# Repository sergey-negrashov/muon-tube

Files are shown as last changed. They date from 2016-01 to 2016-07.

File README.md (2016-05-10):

# MuonTube. Geiger based muon detector for art and science. 
In this project I aim to design and develop a standalone muon detector using old Soviet STS-5  Geiger tubes.  Geometry is shown bellow:
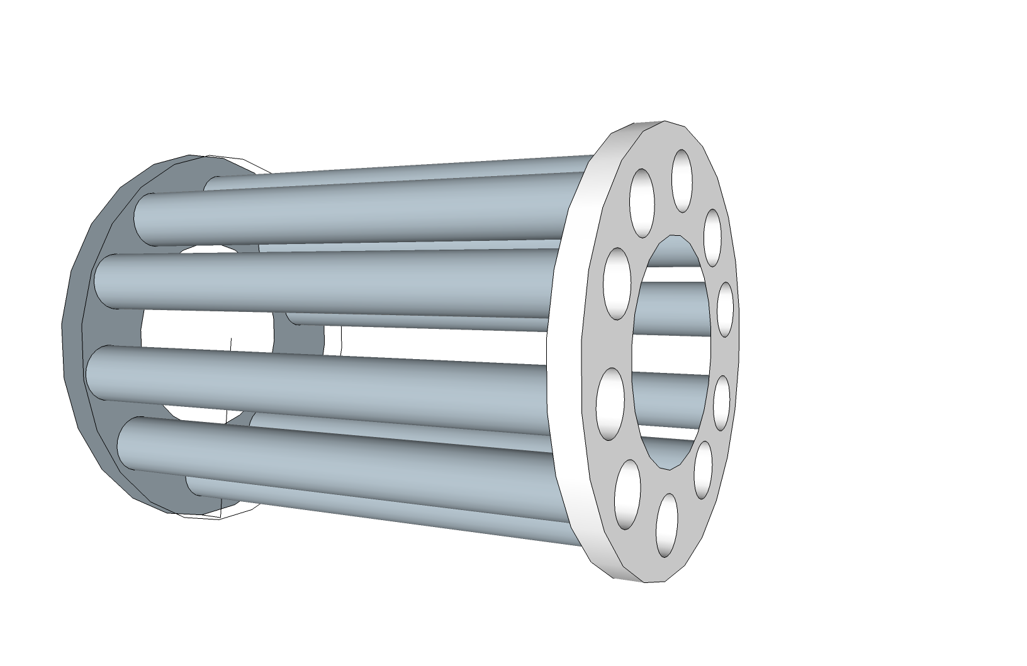
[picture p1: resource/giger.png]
Geiger Detector Geometry


# Roadmap:
1. Power supply design. (Done)
2. Data acquisition design. (Work in progress)
3. Mechanical design. (Started)
4. Integration.

I intend to use custom electronics for the PSU and DAQ. Most likely driven by an FPGA. 
PDF for the PSU and the bias circuit for the GM tube now available [obsolete new one comming soon](https://github.com/sergey-negrashov/muon-tube/raw/master/Schematics/PSU.pdf)

# Goodies 
Geiger tube cage:
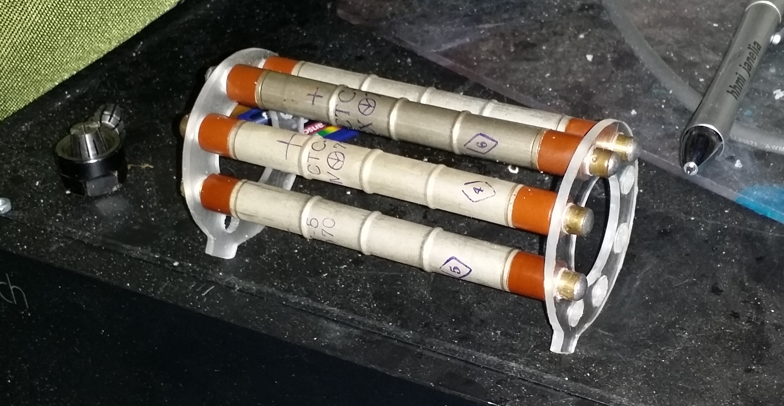
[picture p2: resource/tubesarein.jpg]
Geiger Geiger tube cage


Freshly milled HV PSU board:
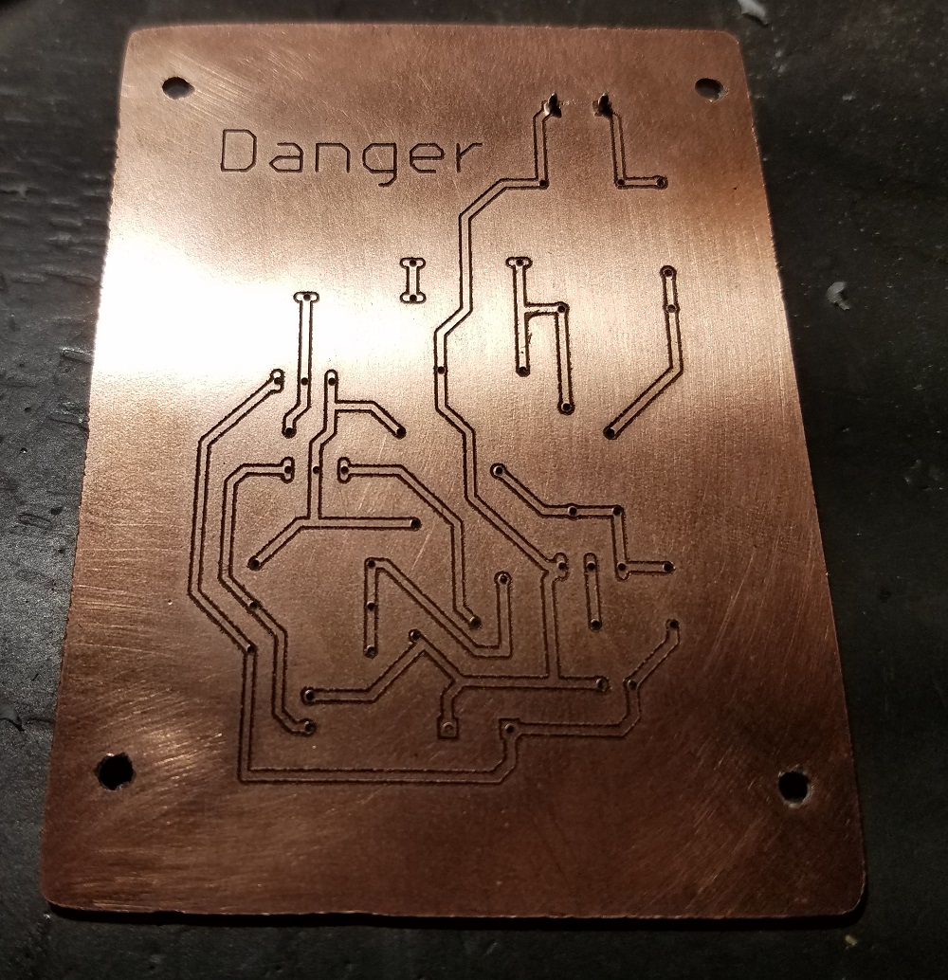
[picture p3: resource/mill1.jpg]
Geiger Freshly milled HV PSU board


First Muons?

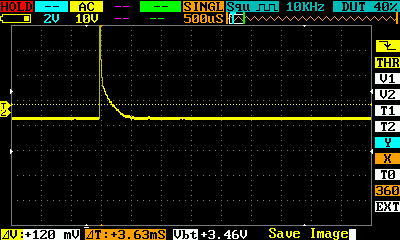
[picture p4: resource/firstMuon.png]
Muon First Muon


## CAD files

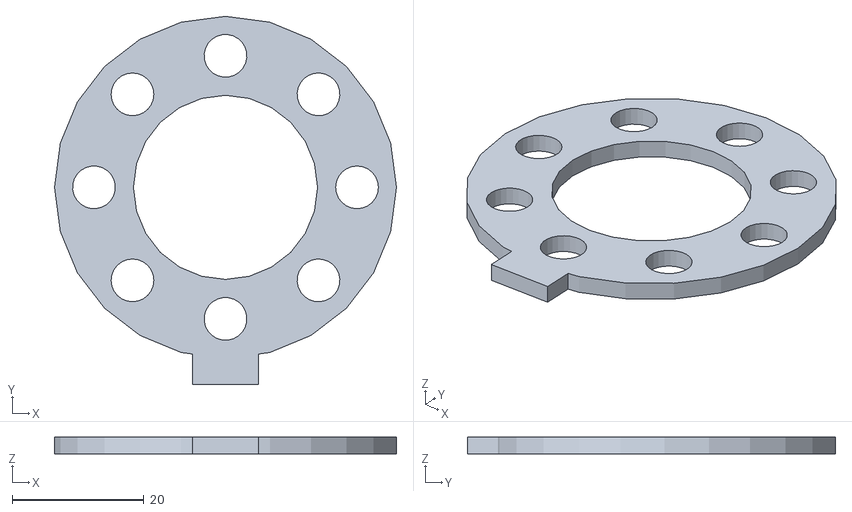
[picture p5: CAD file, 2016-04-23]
Mechanical/cylinder.stl
52.0 x 56.0 x 2.54

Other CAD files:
Mechanical/cylinder.skp

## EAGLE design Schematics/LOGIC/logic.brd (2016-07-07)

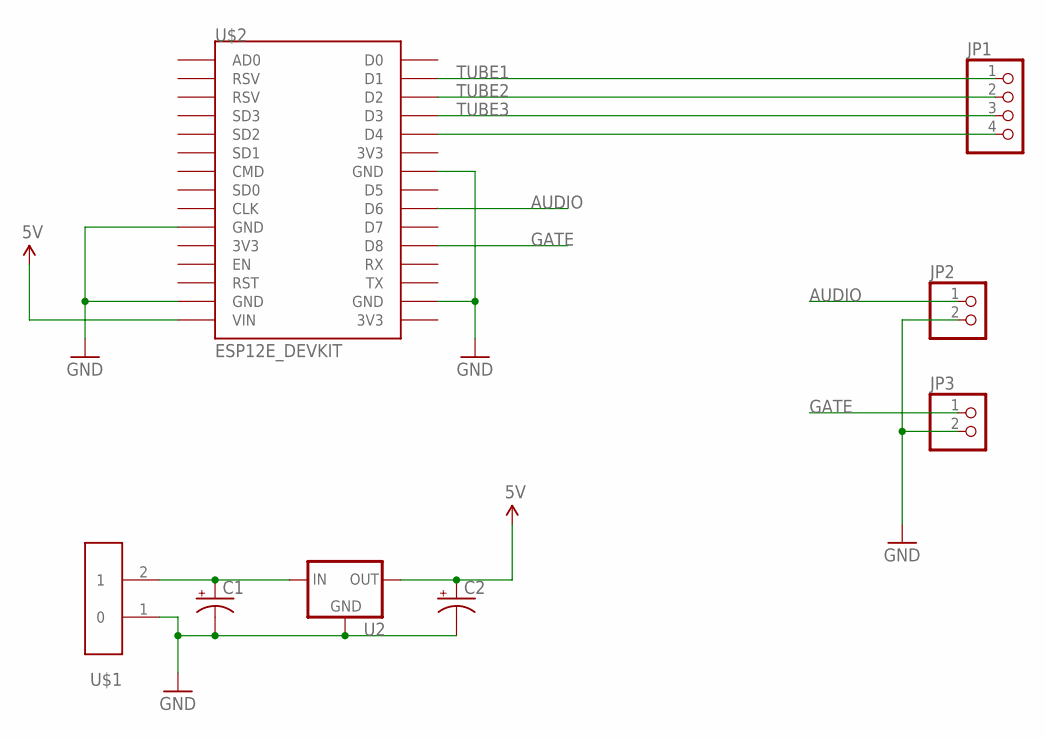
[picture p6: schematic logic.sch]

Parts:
C1, C2: 10UF-25V-20%(PTH); CPOL-RADIAL-10UF-25V
JP1: PINHD-1X4; 1X04
JP2, JP3: PINHD-1X2; 1X02
U2: V_REG_78XXSINK; TO220-IGO
U$1: ED2609
U$2: ESP12E_DEVKIT

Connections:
5V: C2.1 (+), U2.OUT, U$2.VIN
AUDIO: JP2.1, U$2.D6
GATE: JP3.1, U$2.D8
GND: C1.2 (-), C2.2 (-), JP2.2, JP3.2, U2.GND, U$1.1 (0), U$2.GND@0 (GND), U$2.GND@1 (GND), U$2.GND@2 (GND), U$2.GND@3 (GND)
unnamed: C1.1 (+), U2.IN, U$1.2 (1)
unnamed: JP1.4, U$2.D4
TUBE1: JP1.1, U$2.D1
TUBE2: JP1.2, U$2.D2
TUBE3: JP1.3, U$2.D3

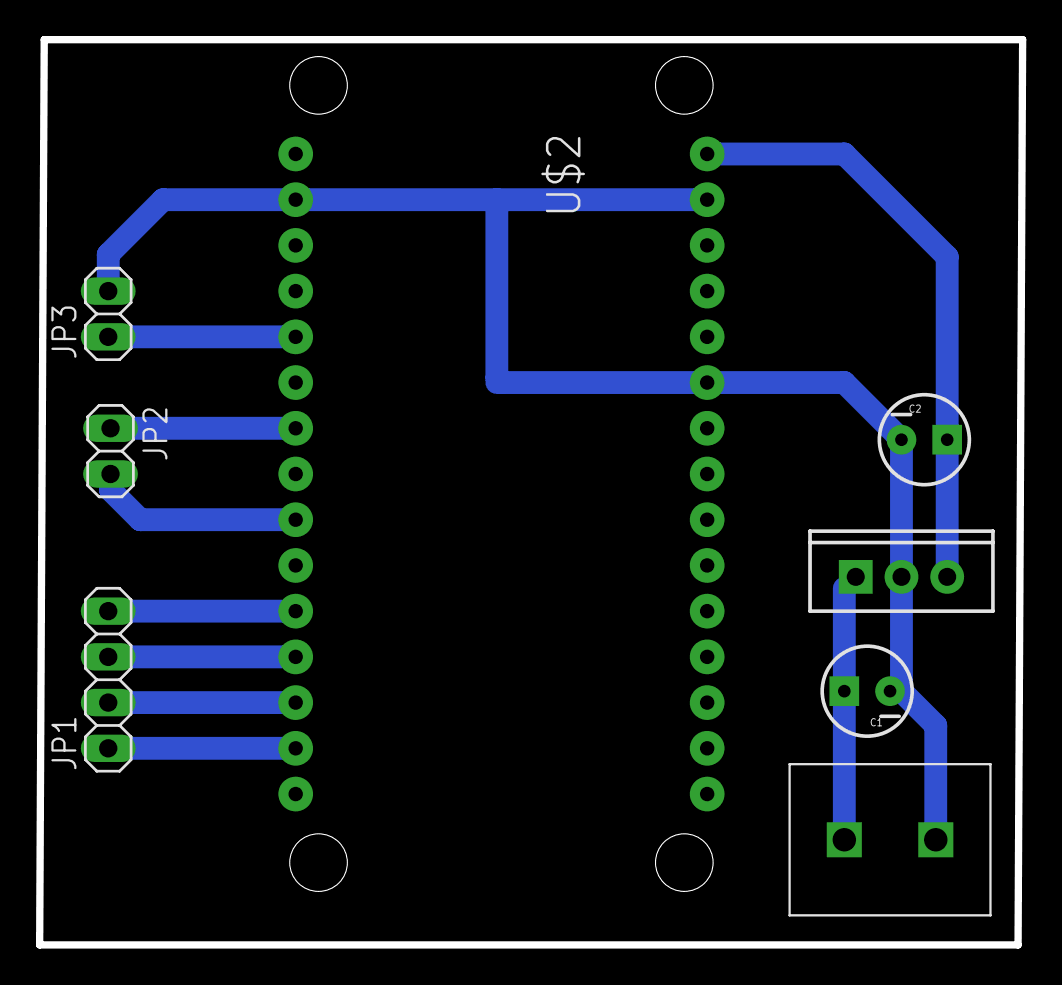
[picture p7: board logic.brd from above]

Board: 2 copper layers, 54.6 x 50.3 mm, 8 parts (0 on the bottom side), 9 nets.

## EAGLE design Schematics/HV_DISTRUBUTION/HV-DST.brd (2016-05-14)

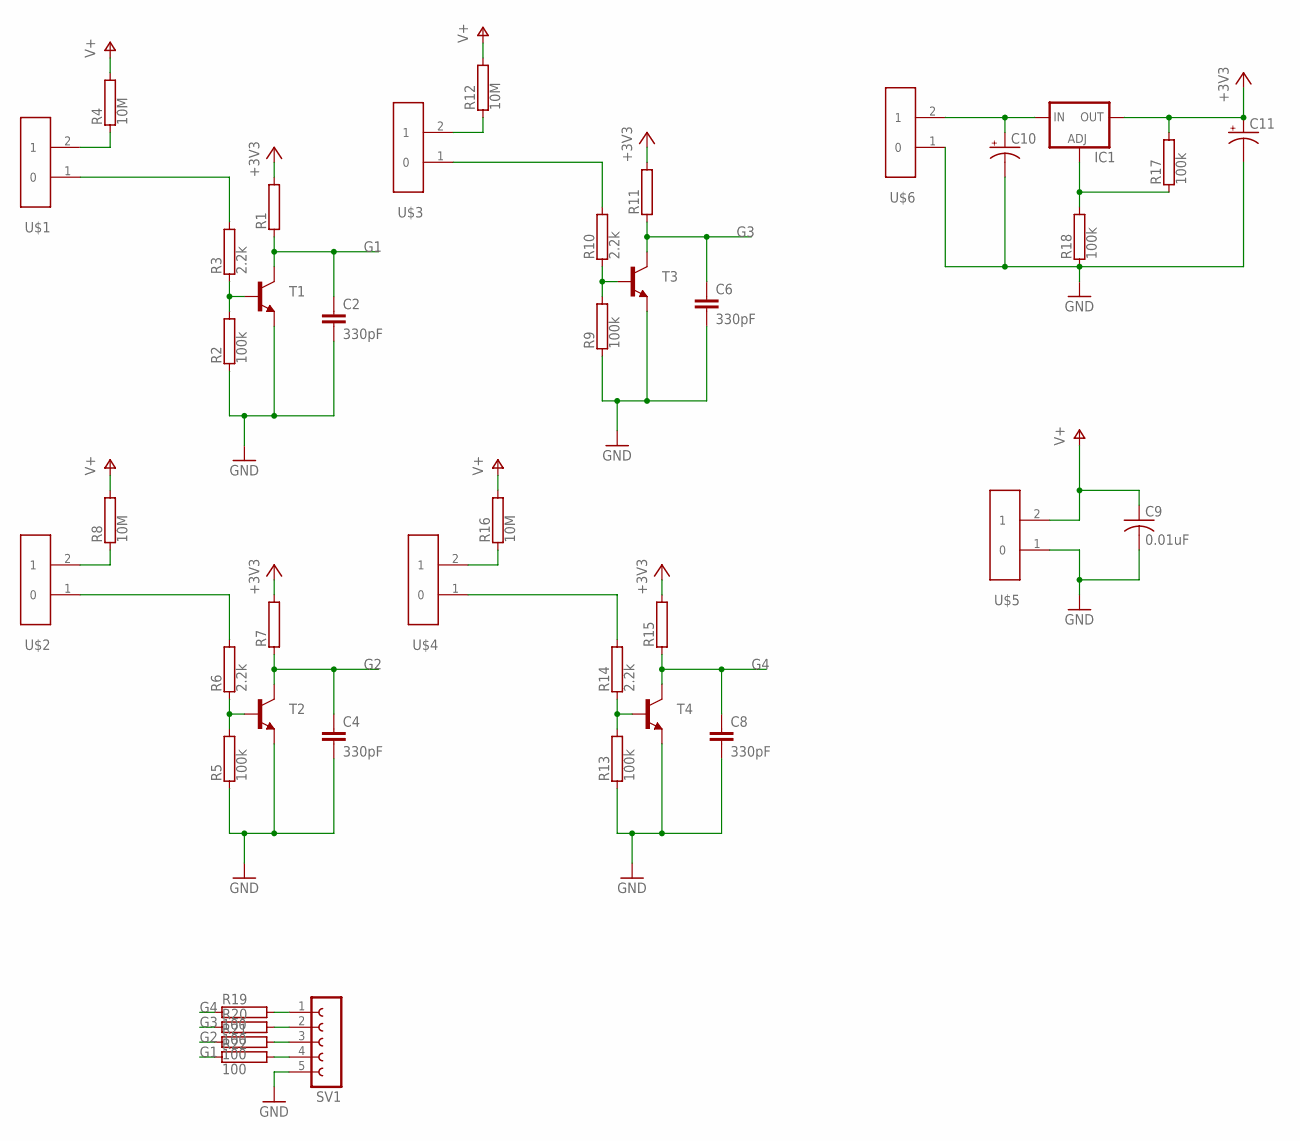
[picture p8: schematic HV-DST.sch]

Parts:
C2, C4, C6, C8: 330pF; C2.5-2
C9: 0.01uF; C075-032X103
C10, C11: CPOL-USE2.5-5; E2,5-5
IC1: LM317TS; 317TS
R1, R7, R11, R15: RRS1/4; RS1/4
R2, R5, R9, R13, R17, R18: 100k; RS1/4
R3, R6, R10, R14: 2.2k; RS1/4
R4, R8, R12, R16: 10M; RS1/4
R19, R20, R21, R22: 100; RS1/4
SV1: FE05-1
T1, T2, T3, T4: 2N5551-NPN-TO92-CBE; TO92-CBE
U$1, U$2, U$3, U$4, U$5, U$6: ED2609

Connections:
+3V3: C11.+, IC1.2 (OUT), R1.2, R7.2, R11.2, R15.2, R17.2
G1: C2.1, R1.1, R22.1, T1.C
G2: C4.1, R7.1, R21.1, T2.C
G3: C6.1, R11.1, R20.1, T3.C
G4: C8.1, R15.1, R19.1, T4.C
GND: C2.2, C4.2, C6.2, C8.2, C9.2, C10.-, C11.-, R2.1, R5.1, R9.1, R13.1, R18.1, SV1.5, T1.E, T2.E, T3.E, T4.E, U$5.1 (0), U$6.1 (0)
unnamed: R2.2, R3.1, T1.B
unnamed: R3.2, U$1.1 (0)
unnamed: C10.+, IC1.3 (IN), U$6.2 (1)
unnamed: R4.1, U$1.2 (1)
unnamed: R5.2, R6.1, T2.B
unnamed: R6.2, U$2.1 (0)
unnamed: R19.2, SV1.1
unnamed: R8.1, U$2.2 (1)
unnamed: R9.2, R10.1, T3.B
unnamed: R10.2, U$3.1 (0)
unnamed: IC1.1 (ADJ), R17.1, R18.2
unnamed: R12.1, U$3.2 (1)
unnamed: R13.2, R14.1, T4.B
unnamed: R14.2, U$4.1 (0)
unnamed: R20.2, SV1.2
unnamed: R16.1, U$4.2 (1)
unnamed: R21.2, SV1.3
unnamed: R22.2, SV1.4
V+: C9.1, R4.2, R8.2, R12.2, R16.2, U$5.2 (1)

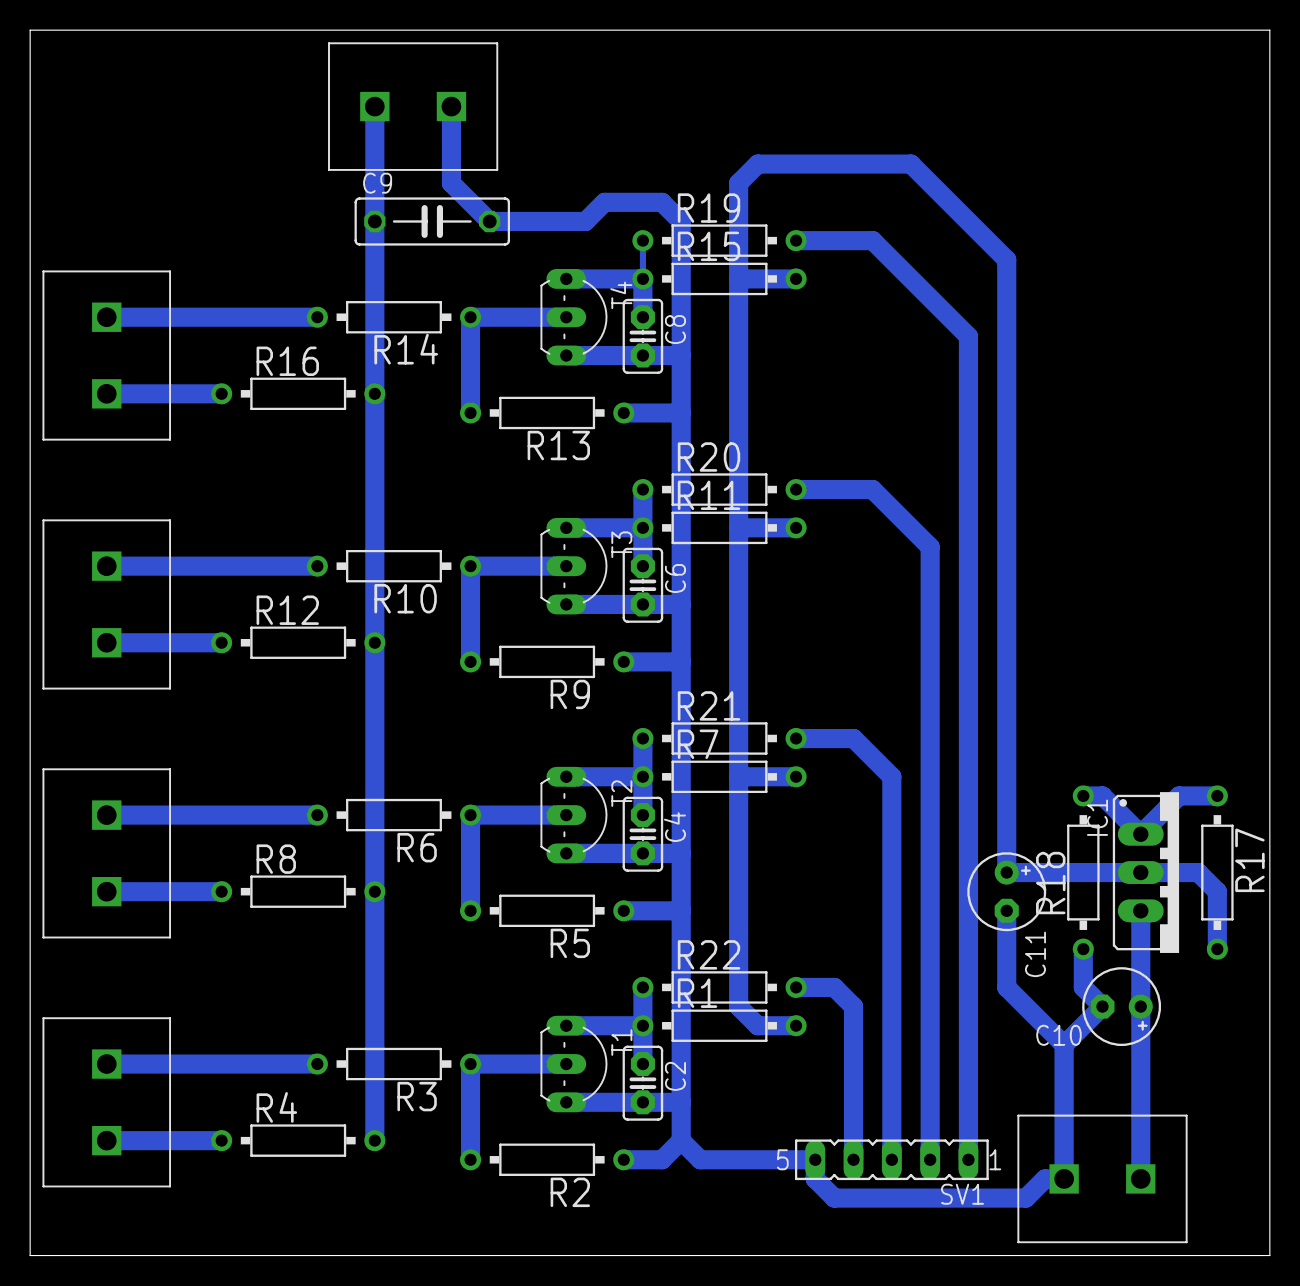
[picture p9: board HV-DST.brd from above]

Board: 2 copper layers, 82.2 x 81.3 mm, 41 parts (0 on the bottom side), 25 nets.

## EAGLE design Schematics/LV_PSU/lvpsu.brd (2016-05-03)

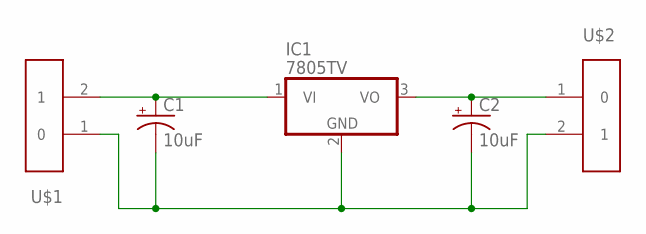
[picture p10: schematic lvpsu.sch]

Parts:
C1, C2: 10uF; E2,5-5
IC1: 7805TV; TO220V
U$1, U$2: ED2609

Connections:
unnamed: C1.+, IC1.1 (VI), U$1.2 (1)
unnamed: C2.+, IC1.3 (VO), U$2.1 (0)
unnamed: C1.-, C2.-, IC1.2 (GND), U$1.1 (0), U$2.2 (1)

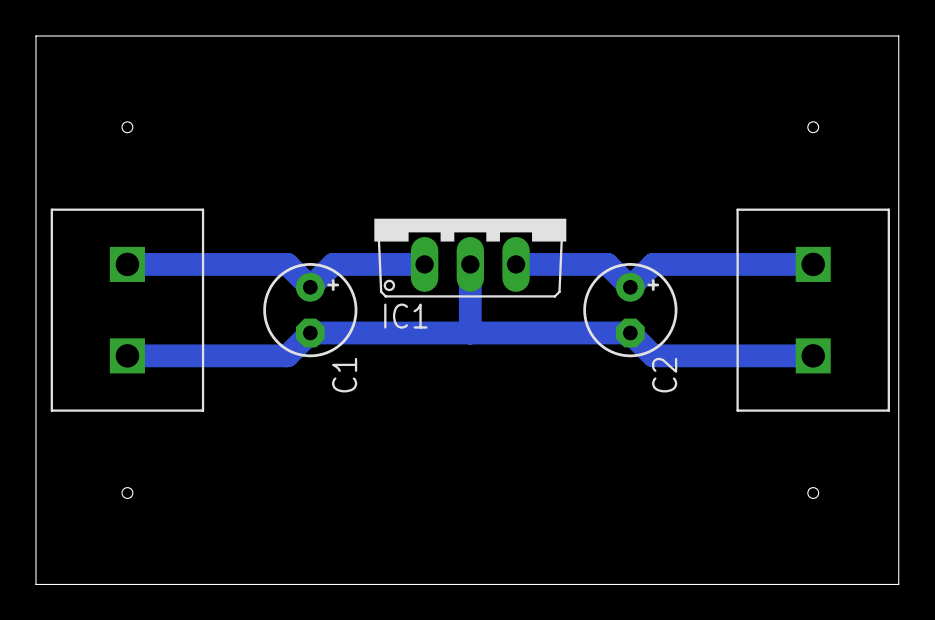
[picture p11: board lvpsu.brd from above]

Board: 2 copper layers, 47.9 x 30.5 mm, 5 parts (0 on the bottom side), 3 nets.

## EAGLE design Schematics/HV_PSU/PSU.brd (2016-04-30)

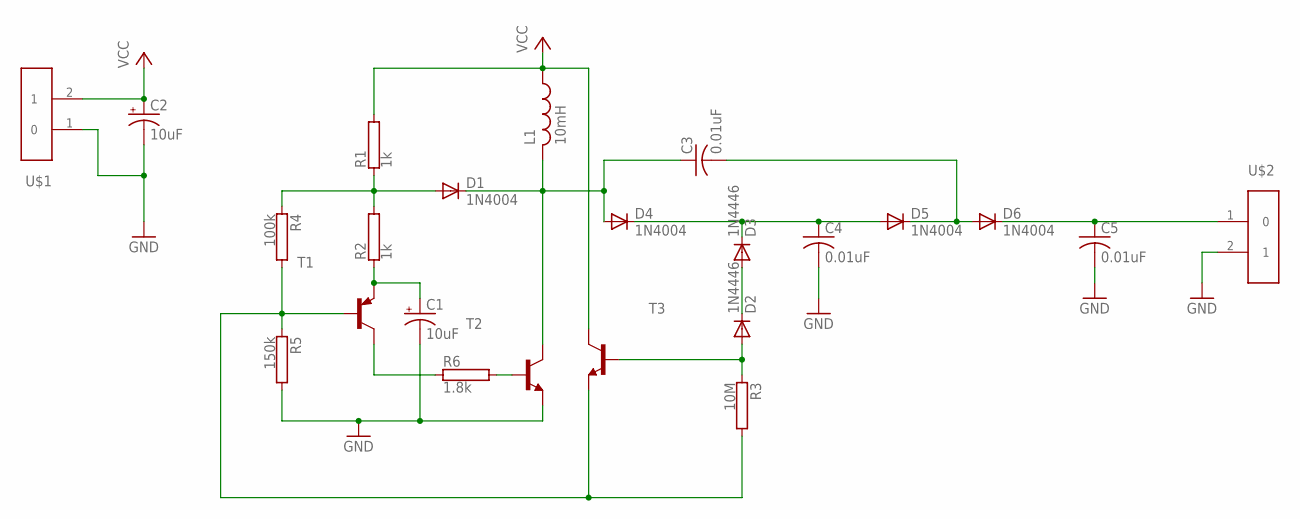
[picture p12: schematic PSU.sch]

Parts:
C1, C2: 10uF; E2,5-5
C3, C4, C5: 0.01uF; C075-032X103
D1, D4, D5, D6: 1N4004; DO41-10
D2, D3: 1N4446; DO35-10
L1: 10mH; 0207/5V
R1, R2: 1k; RS1/4
R3: 10M; RS1/4
R4: 100k; RS1/4
R5: 150k; RS1/4
R6: 1.8k; RS1/4
T1: 2N4403-PNP-TO92-EBC; TO92-EBC
T2: MPSA42-NPN-TO92-EBC; TO92-EBC
T3: MPSA18-NPN-TO92-EBC; TO92-EBC
U$1, U$2: ED2609

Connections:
GND: C1.-, C2.-, C4.2, C5.2, R5.2, T2.E, U$1.1 (0), U$2.2 (1)
unnamed: D1.A, R1.1, R2.2, R4.1
unnamed: D2.A, R3.1, T3.B
unnamed: R3.2, R4.2, R5.1, T1.B, T3.E
unnamed: C1.+, R2.1, T1.E
unnamed: D2.C, D3.A
unnamed: R6.2, T2.B
unnamed: C3.1, D1.C, D4.A, L1.2, T2.C
unnamed: R6.1, T1.C
unnamed: C4.1, D3.C, D4.C, D5.A
unnamed: C3.2, D5.C, D6.A
unnamed: C5.1, D6.C, U$2.1 (0)
VCC: C2.+, L1.1, R1.2, T3.C, U$1.2 (1)

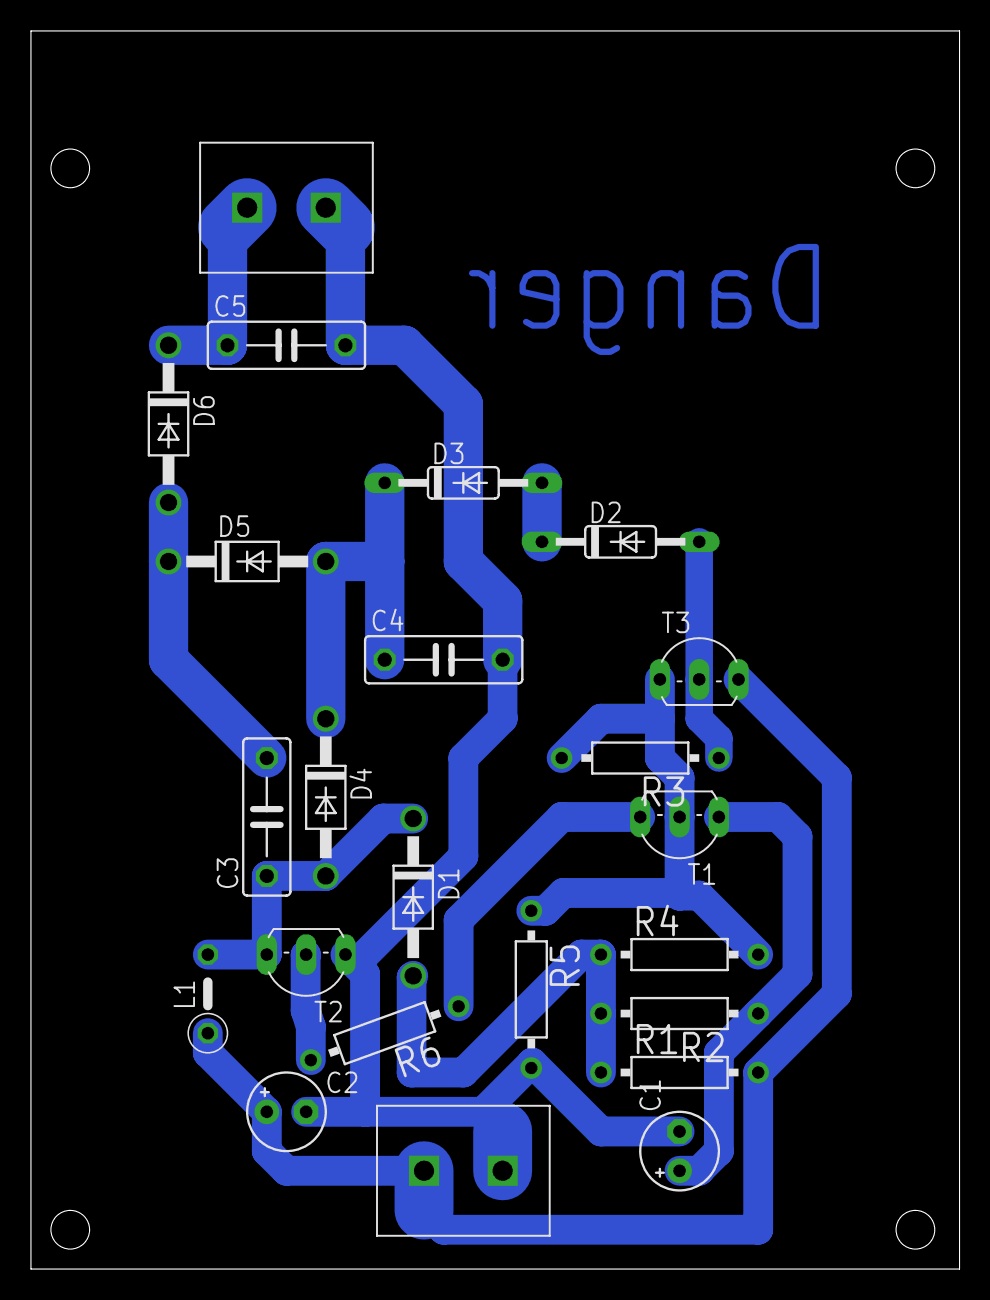
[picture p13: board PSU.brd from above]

Board: 2 copper layers, 60.0 x 80.0 mm, 23 parts (0 on the bottom side), 13 nets.

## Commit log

2016-01-20 Initial import for the schematics
    Setting up the project directory.
    [PSU.sch]
2016-02-01 Finalized the design for the Geiger supply/readout
    [PSU.sch]
2016-02-02 Fixed the cap values in the voltage multiplier
    [PSU.sch]
2016-02-24 Added layout
    [PSU.sch]
2016-03-17 Gieger tubes are in
2016-03-31 Added the milled PSU board drawing
2016-04-23 HV PSU eagle
    [PSU.brd, PSU.sch, cylinder.skp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]
2016-04-23 out with the old
    [PSU.sch]
2016-04-30 Working on the HV distribution board and discriminator
    [HV-DST.brd, HV-DST.sch, PSU.brd]
2016-05-03 Added a 5V degulator PCB.
    [lvpsu.brd, lvpsu.sch]
2016-05-14 Working on layout for distribution
    [HV-DST.brd, HV-DST.sch]
2016-05-14 Finished routing
    [HV-DST.brd, HV-DST.sch]
2016-05-14 Fixed Typo
    [HV-DST.brd, HV-DST.sch]
2016-06-10 Logic board based on ESP12e
    [logic.brd, logic.sch]
2016-06-10 Cleaning up
    [HV-DST.brd, HV-DST.sch]
2016-07-07 Had to redo this board. Could not do 8mill traces on my mill
    [logic.brd, logic.sch]

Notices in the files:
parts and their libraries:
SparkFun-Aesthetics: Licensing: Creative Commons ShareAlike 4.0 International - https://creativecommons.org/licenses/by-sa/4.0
